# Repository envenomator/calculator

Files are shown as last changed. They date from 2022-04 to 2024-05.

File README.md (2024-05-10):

# Barebones AVR m328p based programmer's calculator

I was in need of a no-frills, programmer's calculator, not satisfied with the SwissMicros DM16L clone (which uses RPN), I decided to design my own.
This version powers from a USB micro cable, uses the waveshare 2inch 320x240 color display. Complete insanity, but I like it a lot.

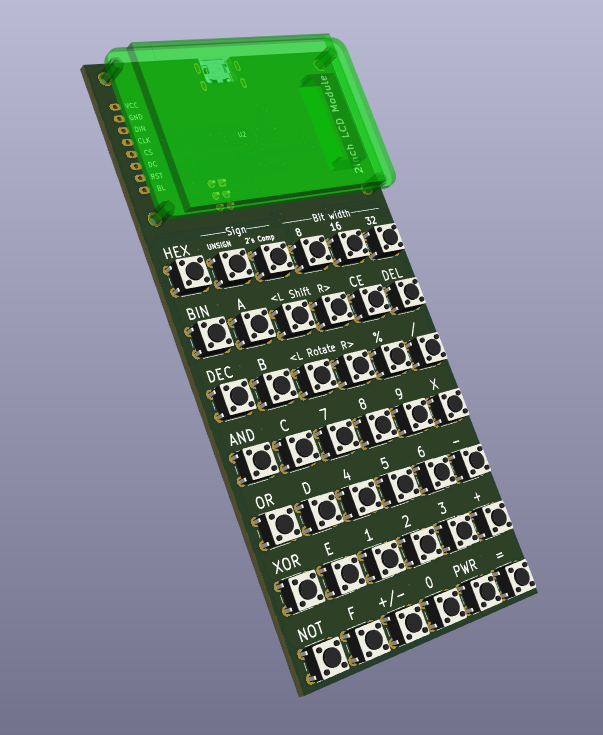
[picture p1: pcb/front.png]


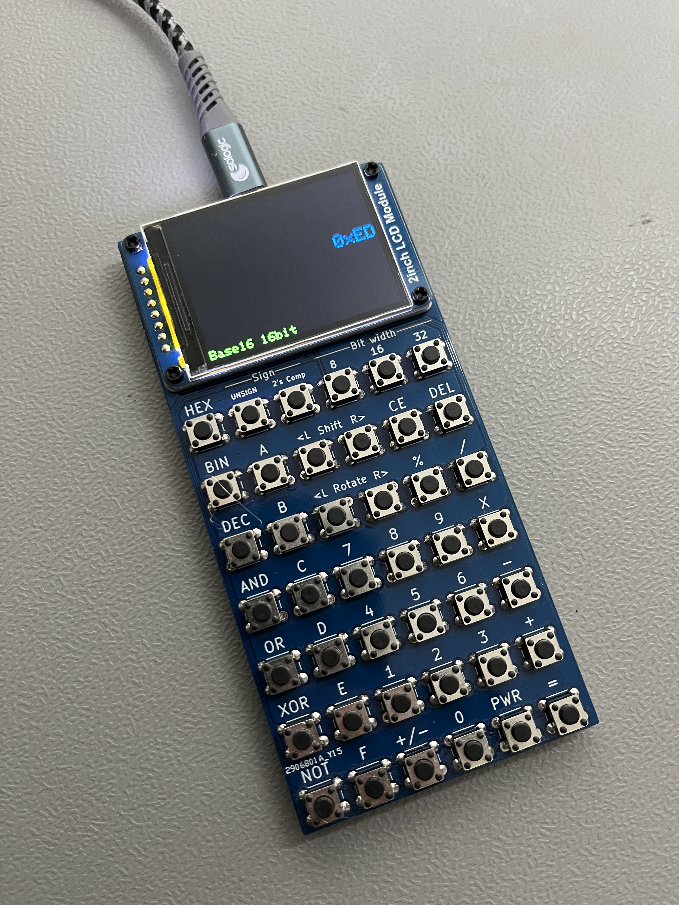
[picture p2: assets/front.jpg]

The display is mounted to the PCB using two 2mm plastic screws, using a 3d printed shim as standoff.


The calculator with it's back plate glued on, programming port accessible.

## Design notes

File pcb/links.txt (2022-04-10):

https://simple-circuit.com/arduino-i2c-lcd-pcf8574/
https://webshop.domoticx.nl/index.php?route=product/product&product_id=266

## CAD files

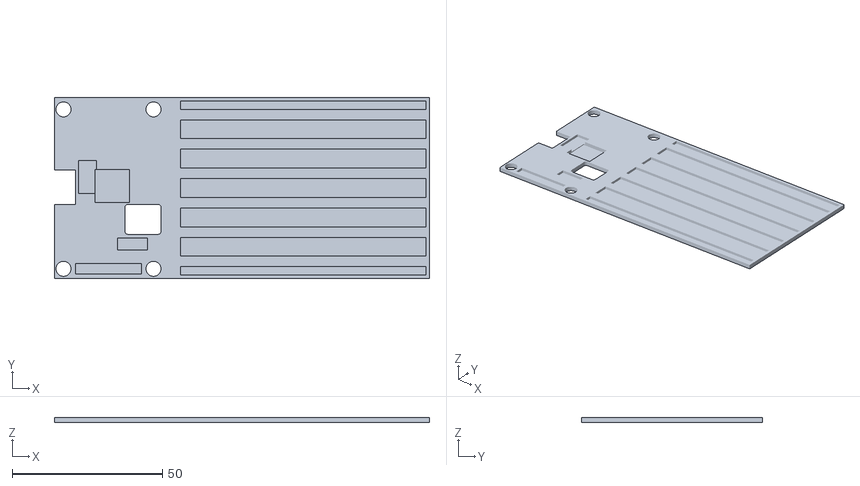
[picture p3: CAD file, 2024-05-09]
Calculator_bottom.stl
125.0 x 60.4 x 1.80

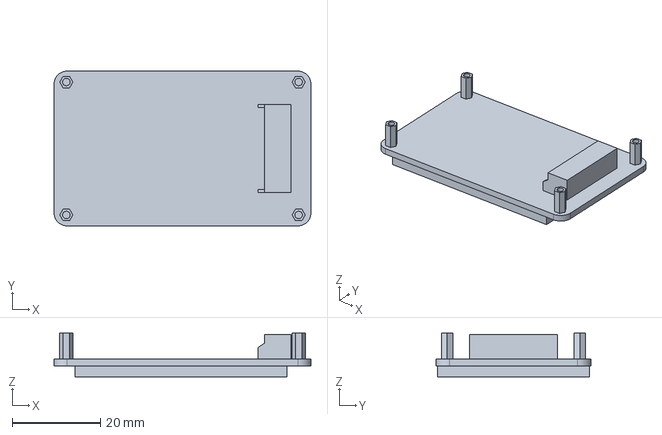
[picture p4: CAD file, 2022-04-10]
pcb/2inch LCD Module 3D Drawing/1018a.stp
58.4 x 35.2 x 9.90 mm

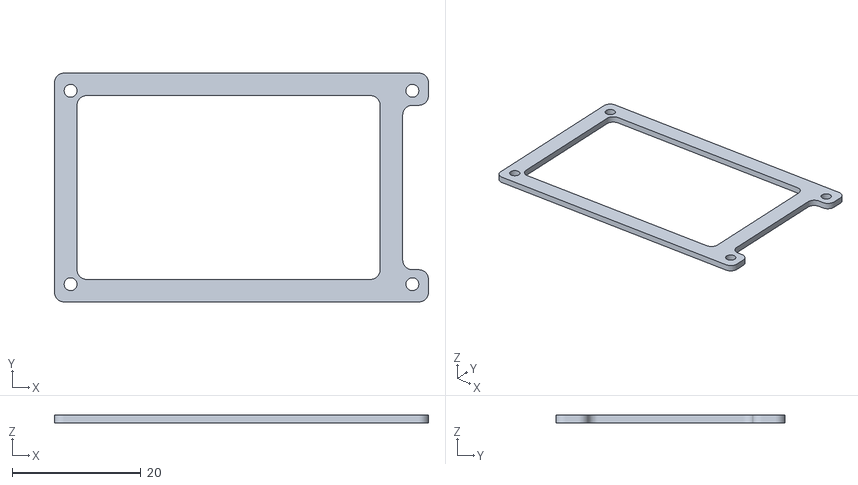
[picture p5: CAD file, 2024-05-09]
LCD_shim_calculator v4.stl
58.0 x 35.5 x 1.20

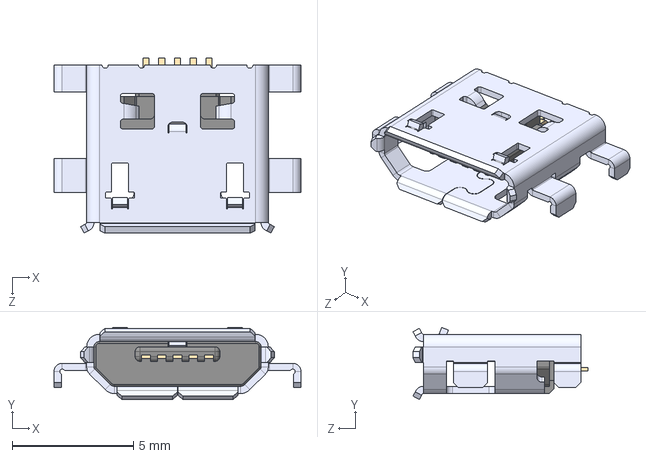
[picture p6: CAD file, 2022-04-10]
pcb/47642-0001/47642-0001.step
10.2 x 2.97 x 7.23 mm

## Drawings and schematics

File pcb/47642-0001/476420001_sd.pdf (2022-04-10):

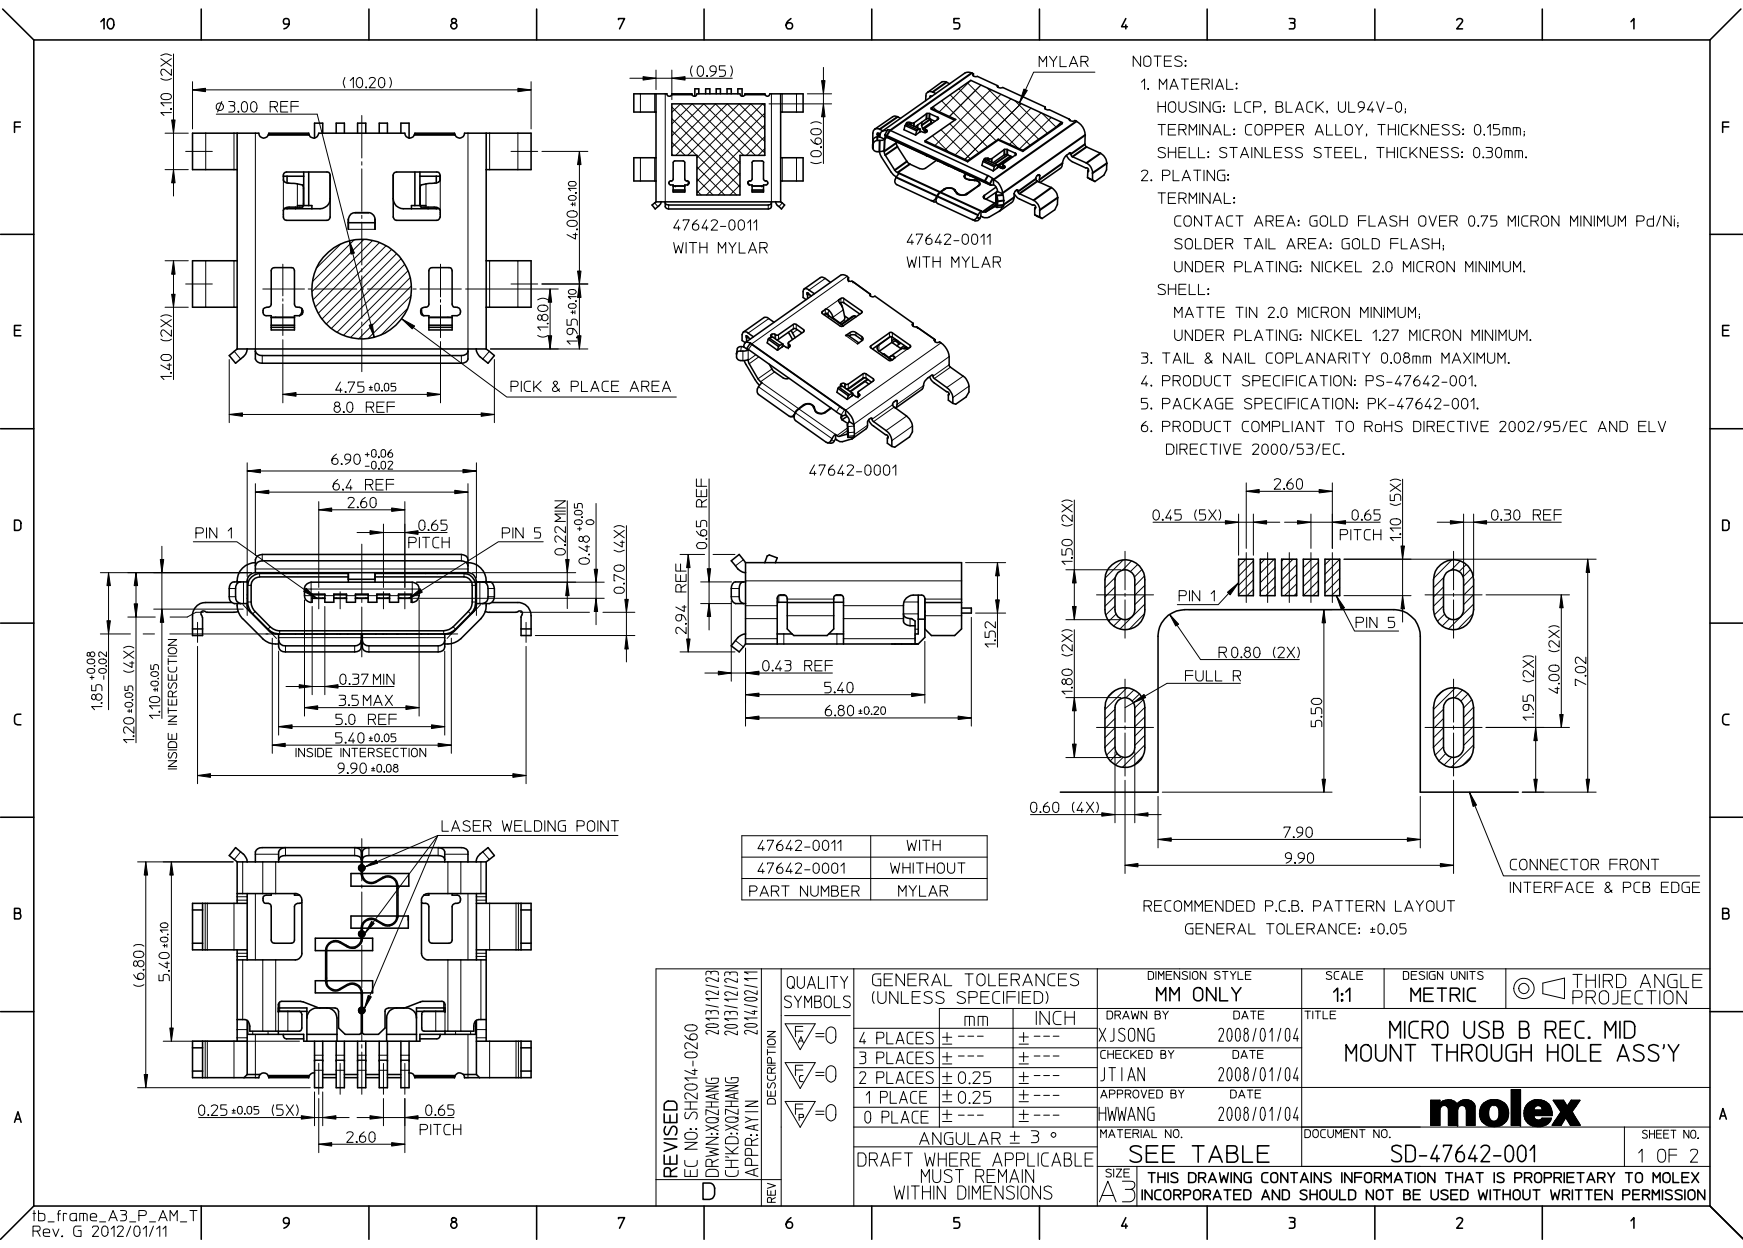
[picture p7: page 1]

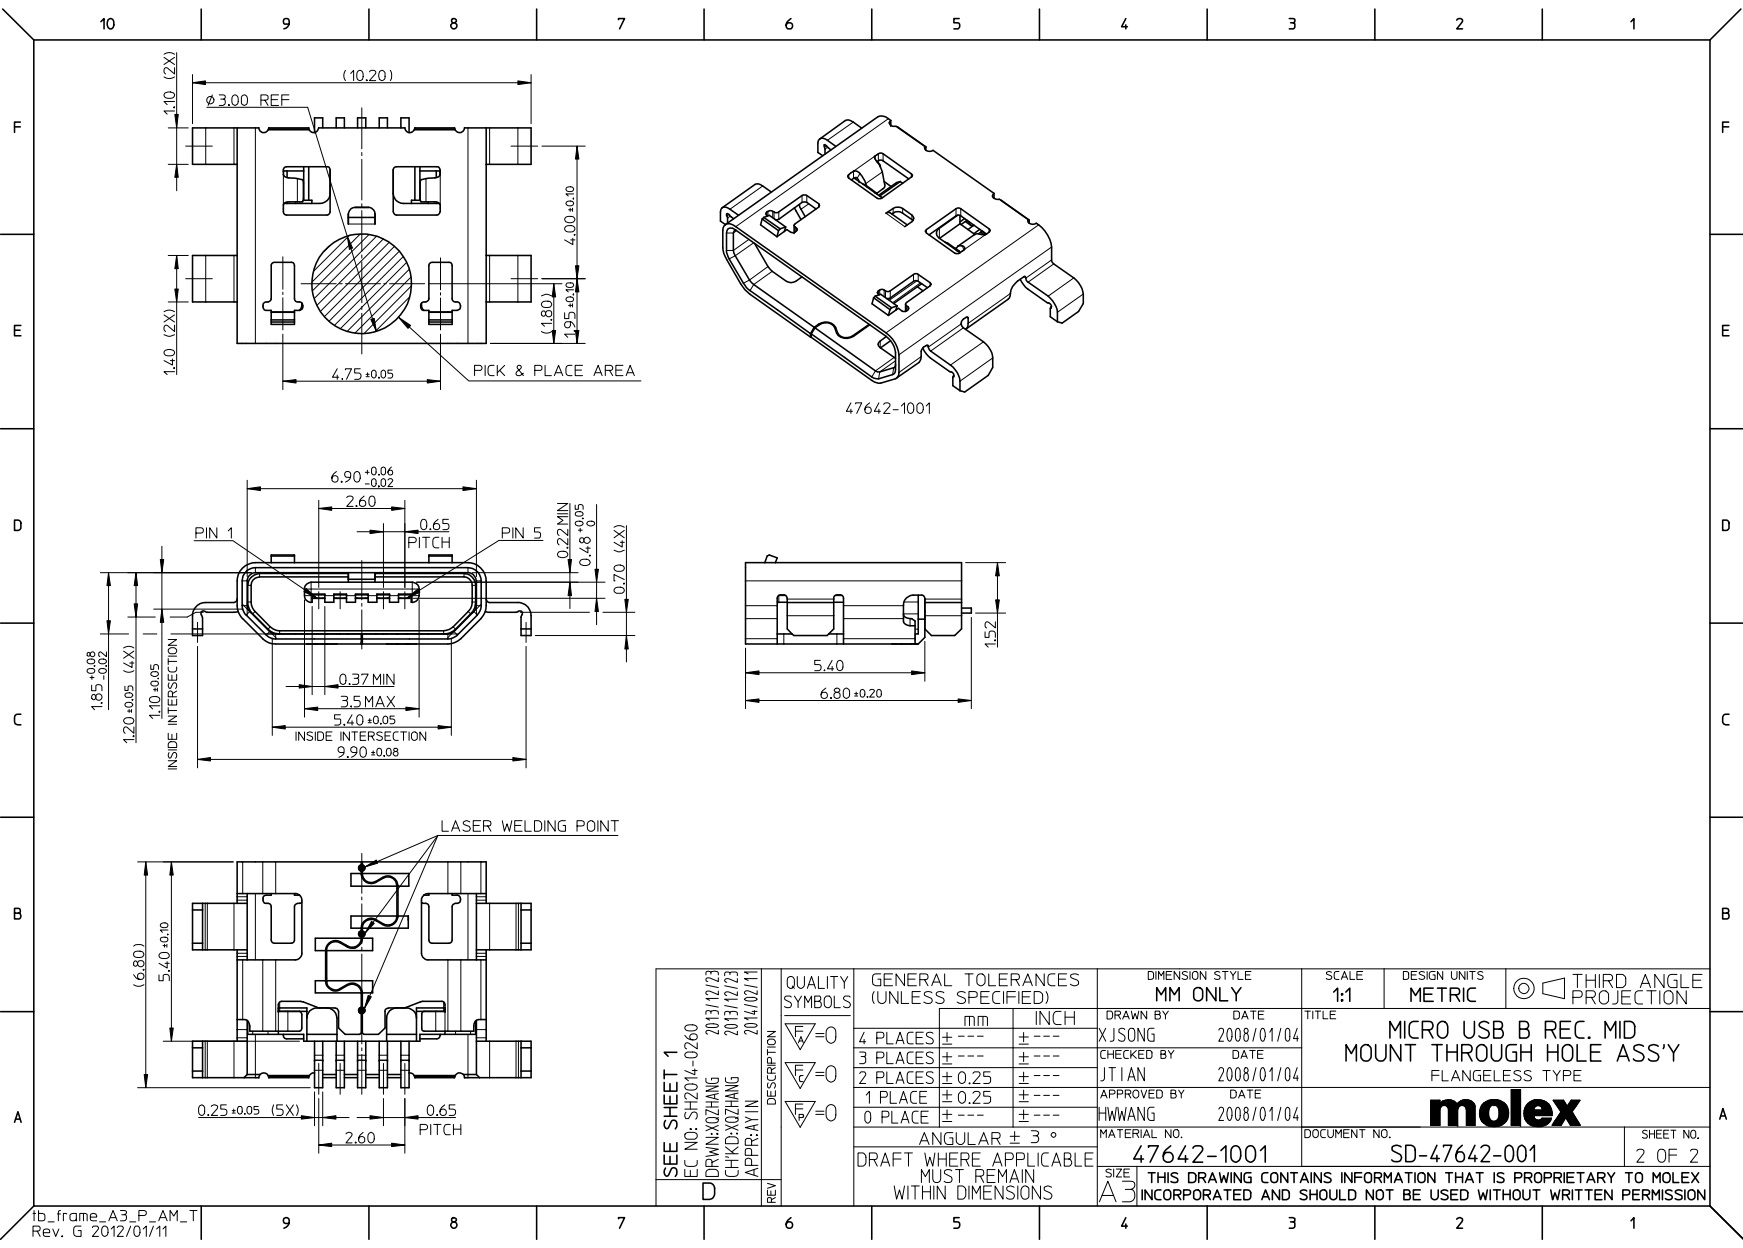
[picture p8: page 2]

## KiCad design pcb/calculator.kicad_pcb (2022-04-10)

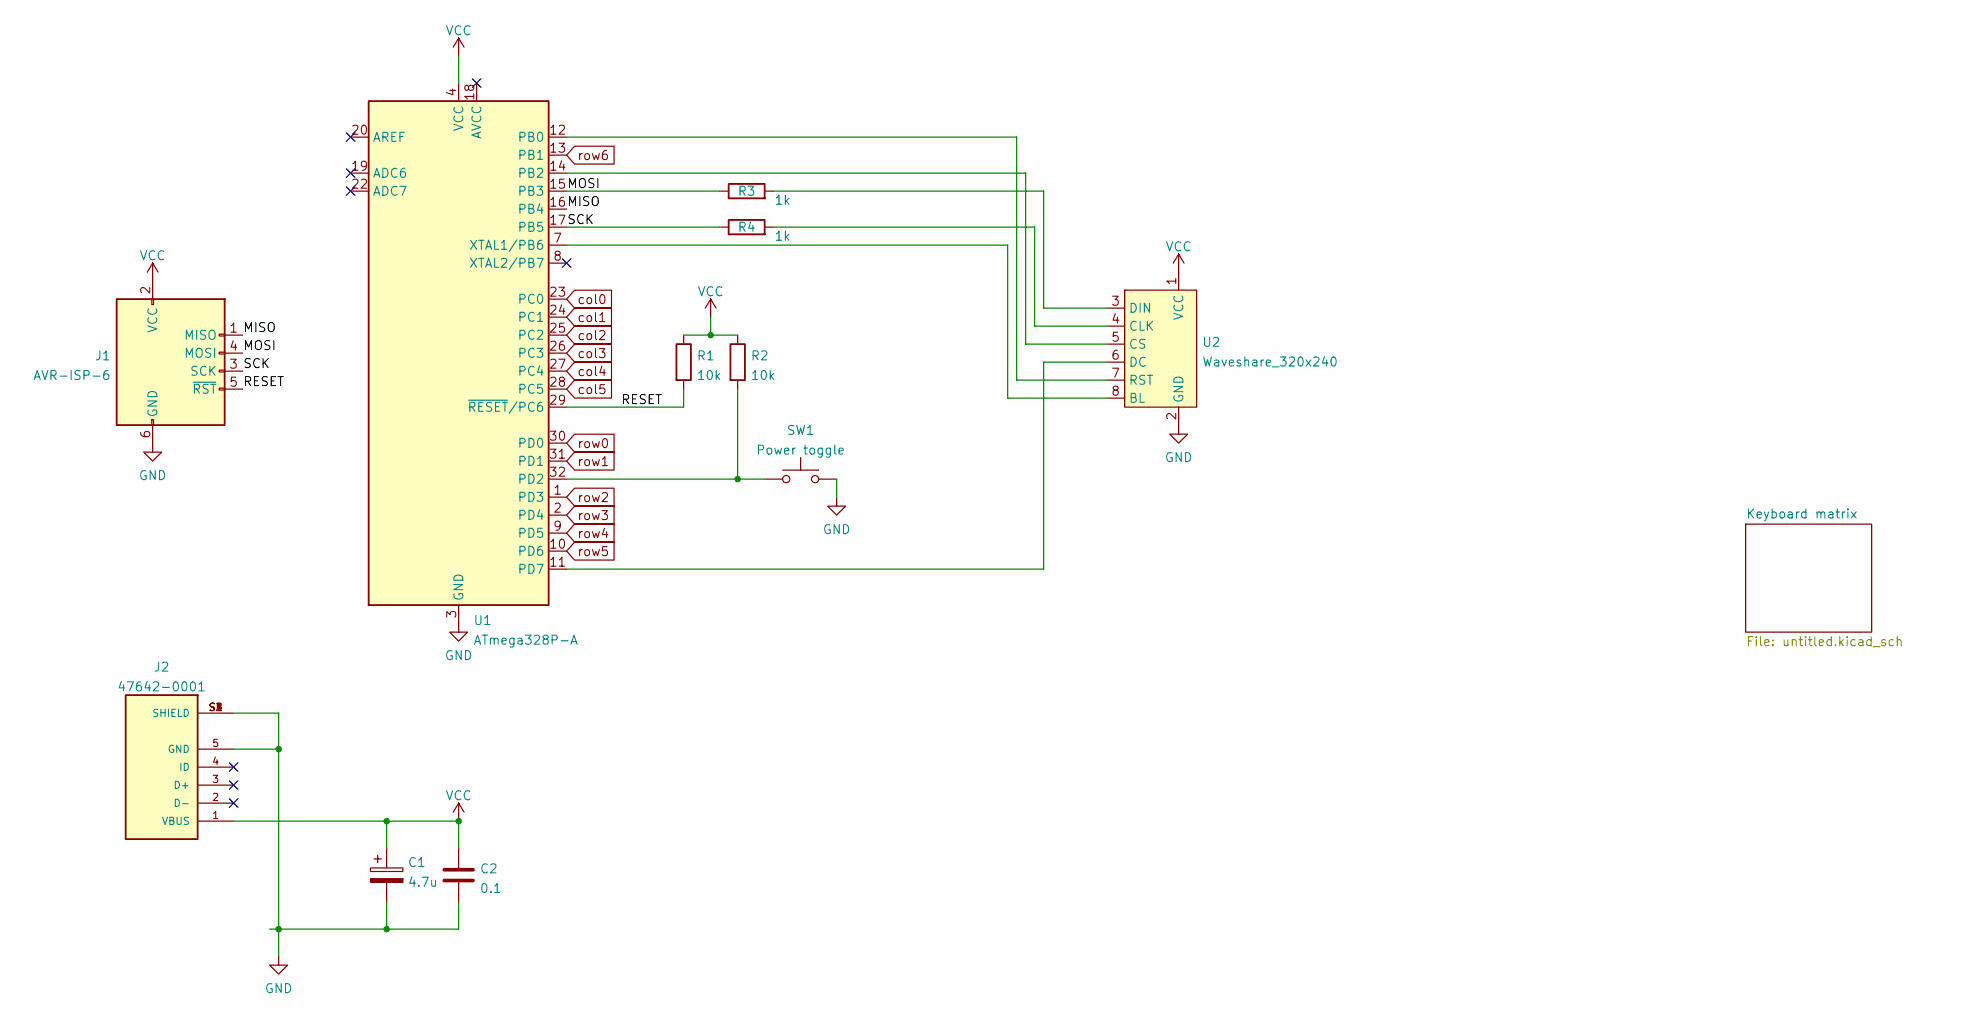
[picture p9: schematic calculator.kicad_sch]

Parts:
C1: 4.7u; C_0805_2012Metric_Pad1.18x1.45mm_HandSolder
C2: 0.1; C_0805_2012Metric_Pad1.18x1.45mm_HandSolder
J1: AVR-ISP-6; PinHeader_2x03_P2.54mm_Vertical
J2: 47642-0001; MOLEX_47642-0001
R1, R2: 10k; R_0805_2012Metric_Pad1.20x1.40mm_HandSolder
R3, R4: 1k; R_0805_2012Metric_Pad1.20x1.40mm_HandSolder
SW1: Power toggle; SW_PUSH_6mm
U1: ATmega328P-A; TQFP-32_7x7mm_P0.8mm
U2: Waveshare_320x240

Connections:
/MISO: J1.1 (MISO), U1.16 (PB4)
/MOSI: J1.4 (MOSI), R3.1, U1.15 (PB3)
/RESET: J1.5 (~RST), R1.2, U1.29 (~RESET/PC6)
/SCK: J1.3 (SCK), R4.1, U1.17 (PB5)
GND: C1.2, C2.2, J1.6 (GND), J2.5 (GND), J2.S1 (SHIELD), J2.S2 (SHIELD), J2.S3 (SHIELD), J2.S4 (SHIELD), SW1.2, U1.3 (GND), U1.5 (GND), U1.21 (GND), U2.2 (GND)
unnamed: R2.2, SW1.1, U1.32 (PD2)
unnamed: R3.2, U2.3 (DIN)
unnamed: R4.2, U2.4 (CLK)
unnamed: U1.7 (XTAL1/PB6), U2.8 (BL)
unnamed: U1.11 (PD7), U2.6 (DC)
unnamed: U1.12 (PB0), U2.7 (RST)
unnamed: U1.14 (PB2), U2.5 (CS)
VCC: C1.1, C2.1, J1.2 (VCC), J2.1 (VBUS), R1.1, R2.1, U1.4 (VCC), U1.6 (VCC), U2.1 (VCC)
col0: U1.23 (PC0); also elsewhere on the board
col1: U1.24 (PC1); also elsewhere on the board
col2: U1.25 (PC2); also elsewhere on the board
col3: U1.26 (PC3); also elsewhere on the board
col4: U1.27 (PC4); also elsewhere on the board
col5: U1.28 (PC5); also elsewhere on the board
row0: U1.30 (PD0); also elsewhere on the board
row1: U1.31 (PD1); also elsewhere on the board
row2: U1.1 (PD3); also elsewhere on the board
row3: U1.2 (PD4); also elsewhere on the board
row4: U1.9 (PD5); also elsewhere on the board
row5: U1.10 (PD6); also elsewhere on the board
row6: U1.13 (PB1); also elsewhere on the board

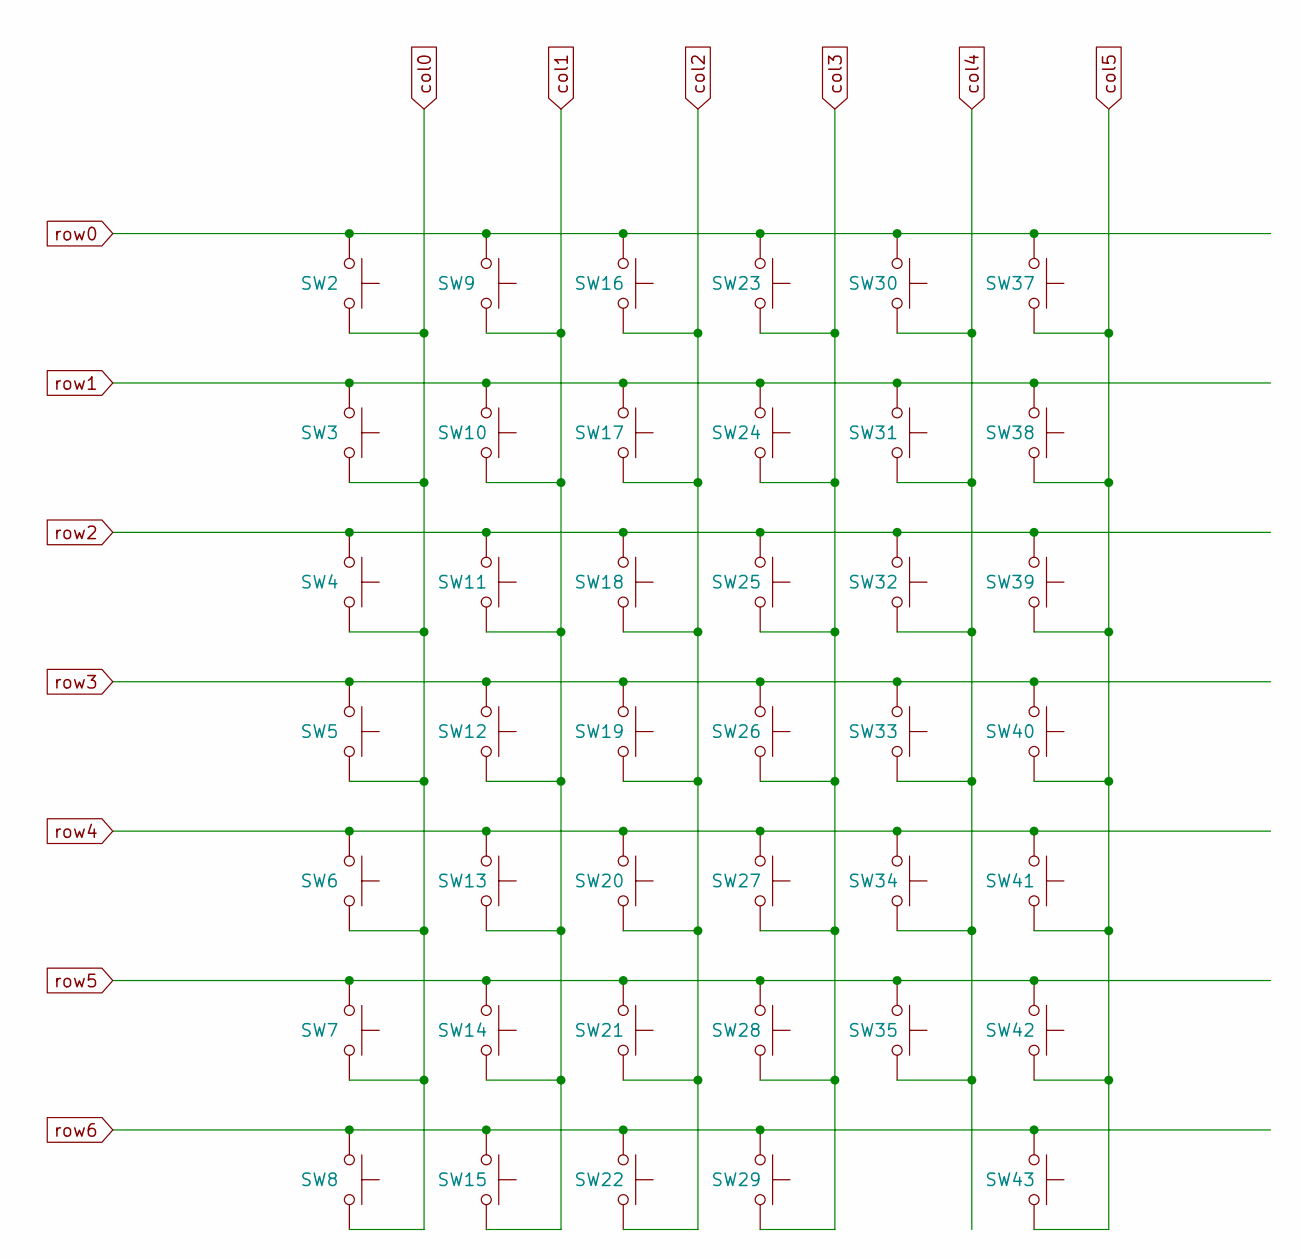
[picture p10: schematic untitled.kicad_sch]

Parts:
SW2: HEX; SW_PUSH_6mm
SW3, SW4, SW5, SW6, SW7, SW8, SW9, SW10, SW11, SW12, SW13, SW14, SW15, SW16, SW17, SW18, SW19, SW20, SW21, SW22, SW23, SW24, SW25, SW26, SW27, SW28, SW29, SW30, SW31, SW32, SW33, SW34, SW35, SW37, SW38, SW39, SW40, SW41, SW42, SW43: SW_Push; SW_PUSH_6mm

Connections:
col0: SW2.2, SW3.2, SW4.2, SW5.2, SW6.2, SW7.2, SW8.2; also elsewhere on the board
col1: SW9.2, SW10.2, SW11.2, SW12.2, SW13.2, SW14.2, SW15.2; also elsewhere on the board
col2: SW16.2, SW17.2, SW18.2, SW19.2, SW20.2, SW21.2, SW22.2; also elsewhere on the board
col3: SW23.2, SW24.2, SW25.2, SW26.2, SW27.2, SW28.2, SW29.2; also elsewhere on the board
col4: SW30.2, SW31.2, SW32.2, SW33.2, SW34.2, SW35.2; also elsewhere on the board
col5: SW37.2, SW38.2, SW39.2, SW40.2, SW41.2, SW42.2, SW43.2; also elsewhere on the board
row0: SW2.1, SW9.1, SW16.1, SW23.1, SW30.1, SW37.1; also elsewhere on the board
row1: SW3.1, SW10.1, SW17.1, SW24.1, SW31.1, SW38.1; also elsewhere on the board
row2: SW4.1, SW11.1, SW18.1, SW25.1, SW32.1, SW39.1; also elsewhere on the board
row3: SW5.1, SW12.1, SW19.1, SW26.1, SW33.1, SW40.1; also elsewhere on the board
row4: SW6.1, SW13.1, SW20.1, SW27.1, SW34.1, SW41.1; also elsewhere on the board
row5: SW7.1, SW14.1, SW21.1, SW28.1, SW35.1, SW42.1; also elsewhere on the board
row6: SW8.1, SW15.1, SW22.1, SW29.1, SW43.1; also elsewhere on the board

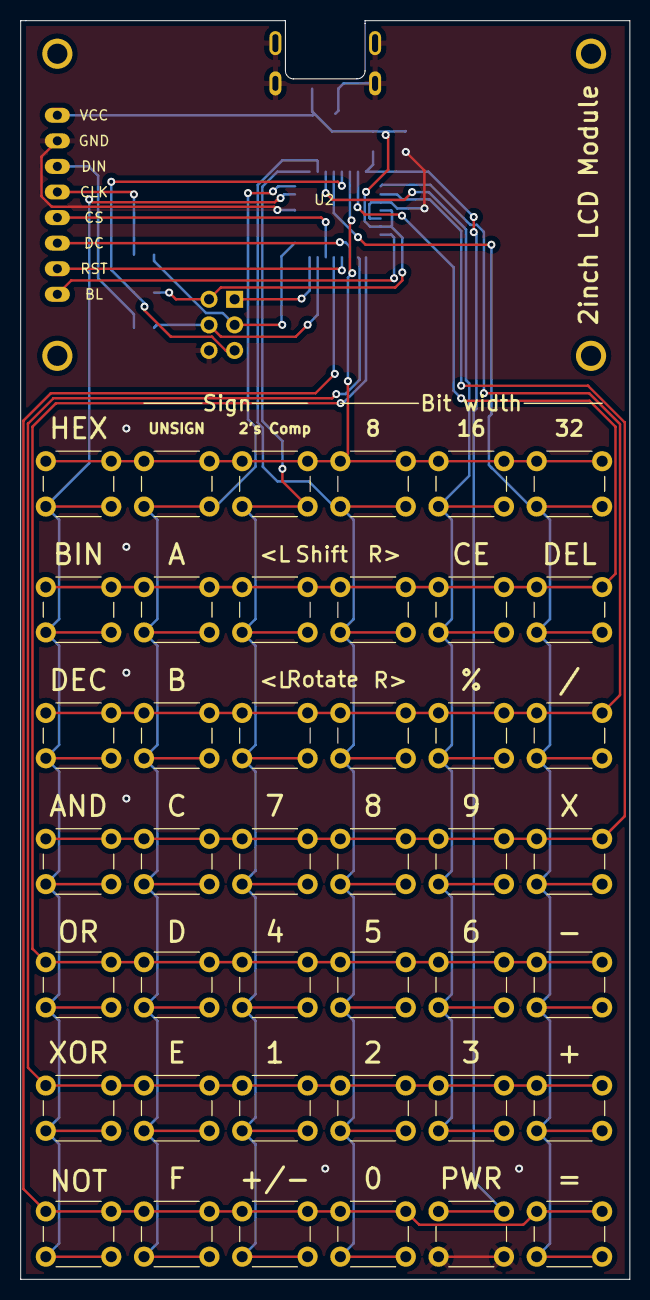
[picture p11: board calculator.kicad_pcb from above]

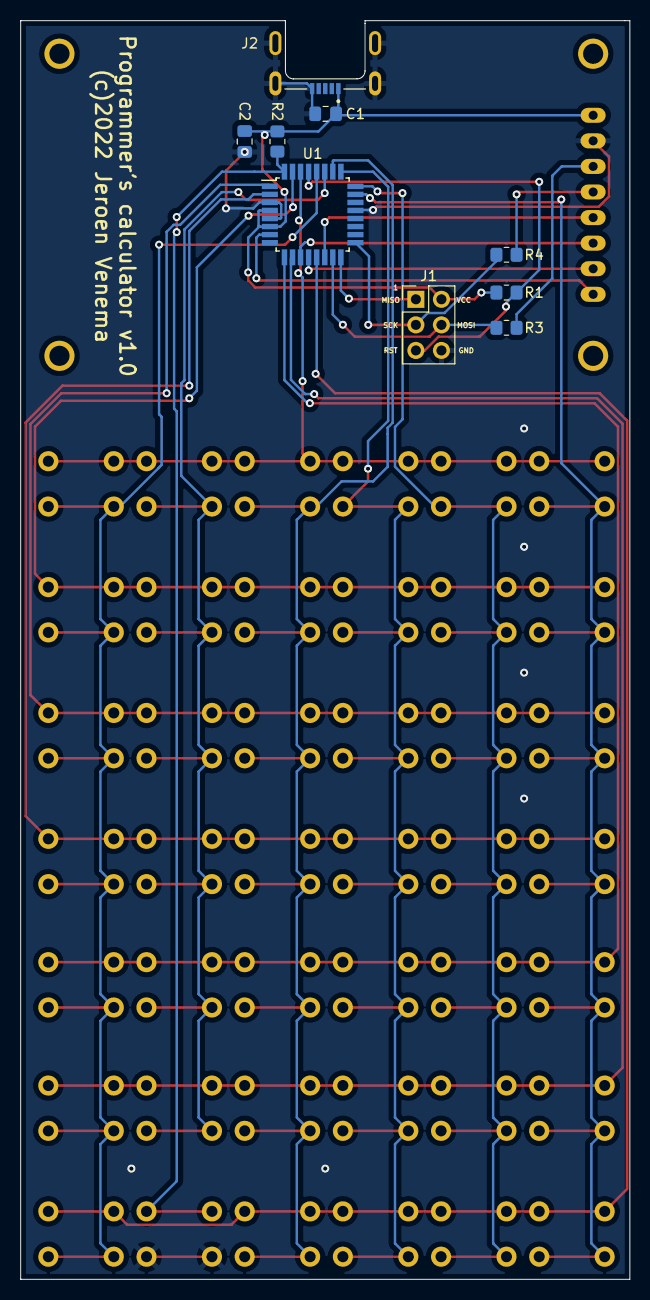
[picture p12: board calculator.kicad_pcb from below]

Board: 2 copper layers, 60.5 x 125.0 mm, 52 parts (9 on the bottom side), 26 nets.

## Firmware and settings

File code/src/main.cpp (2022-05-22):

// GFX library font dimensions, in pixels:
// 1: X/Y: 5+1 / 7+1
// 2: X/Y: 10+2/14+2
// 3: X/Y: 15+3/21+3
// + denotes spacing between glyphs

#include <avr/io.h>
#include <avr/sleep.h>
#include <util/delay.h>
#include <avr/interrupt.h>
#include <avr/power.h>
#include <Arduino.h>
#include <Keypad.h>
#include <Adafruit_GFX.h>    // Core graphics library
#include <Adafruit_ST7789.h> // Hardware-specific library for ST7789
#include <SPI.h>
#include <TimerOne.h>        // used for automatic shutdown timer
#include "displayvalue.h"
#include "inputbox.h"
#include "area.h"
#include "statusmessage.h"
#include "statusflags.h"
#include "operation.h"

// TFT Screen setup
#define TFT_CS        10
#define TFT_RST        8
#define TFT_DC         7
Adafruit_ST7789 tft = Adafruit_ST7789(TFT_CS, TFT_DC, TFT_RST);

// Custom colors
#define TFT_LIGHTGREY 0x9cf3
#define TFT_DARKBLUE  0x0015

// Timer
#define TIMER_US 100000                         // 100mS set timer duration in microseconds 
#define TICK_COUNTS 600                         // 60S worth of timer ticks
volatile long tick_count = TICK_COUNTS;         // Counter for 10S

// Matrix keypad setup
const byte ROWS = 7;
const byte COLS = 6;
char keys[ROWS][COLS] = {   //CAPS and numbers are direct input, lower-case are commands
  {'h','u','s','i','j','k'},
  {'b','A','l','r','c','X'},
  {'d','B','m','n','%','/'},
  {'a','C','7','8','9','*'},
  {'o','D','4','5','6','-'},
  {'x','E','1','2','3','+'},
  {'!','F','^','0','p','='} // p isn't mapped to the grid
};
byte rowPins[ROWS] = {0,1,3,4,5,6,9};
byte colPins[COLS] = {14,15,16,17,18,19};
Keypad keypad = Keypad( makeKeymap(keys), rowPins, colPins, ROWS, COLS );

// value setup
displayValue result(0,status::Hex, 16, false);  // default Decimal mode, start from 0, nothing to show
inputBox input(0,status::Hex,16, false);          // default Decimal mode, start from 0, show value

// status box
statusMessage currentstatus(0, status::Hex, 16, false);
statusFlags flags;
operation op;

void wakeUpNow()
{
}  

void sleepNow()
{
  set_sleep_mode(SLEEP_MODE_PWR_DOWN);
  sleep_enable();
  attachInterrupt(0,wakeUpNow,LOW);
  sleep_mode();
  detachInterrupt(0);
}

// --------------------------
// timerIsr() 100 milli second interrupt ISR()
// Called every time the hardware timer 1 times out.
// --------------------------
void timerIsr()
{
  // count down to zero, don't restart. Main loop will pick up on zero
  if(tick_count) tick_count--;
}

void setup(void) {
  // Screen init
  tft.init(240, 320);           // Init ST7789 320x240
  tft.setRotation(1);
  tft.fillScreen(ST77XX_BLACK);

  // attach screen object and asign area to each output object
  result.init(&tft, area(0,0,319,23), ST77XX_WHITE, TFT_LIGHTGREY);
  flags.init(&tft,area(0,30,319,46), ST77XX_YELLOW);
  op.init(&tft, area(0,75,319,99), ST77XX_BLUE);
  input.init(&tft, area(0,100,319,129), ST77XX_BLUE, TFT_DARKBLUE);
  currentstatus.init(&tft, area(0,224,319,239), ST77XX_GREEN);
  
  // set backlight pin to on
  DDRB |= (1 << 6);
  PORTB |= (1 << 6); // set bit 6 on for backlight (BL)

  // PWR button is an input
  pinMode(2, INPUT);  // PWR button connected to PIN 2

  // show default objects on screen
  input.show();
  currentstatus.show();

  // Countdown timer start
  Timer1.initialize(TIMER_US);                  // Initialise timer 1
  Timer1.attachInterrupt( timerIsr );           // attach the ISR routine here

}

void loop() {
  char key = keypad.getKey();

  if(key)
  {
    tick_count = TICK_COUNTS; // reset timer

    switch(key)
    {
      case '0' ... '9':
      case 'A' ... 'F':
        input.processKeyValue(key);
        break;
      case 'X':
        input.deleteDigit();
        break;
      case 'c': // Clear
        result.hide();
        result.setValue(0); // no results
        op.hide();
        op.set(operation::Method::None);
        flags.hide();
        flags.clearFlags();
        input.setValue(0);
        break;
      case 'h':
        currentstatus.setBase(status::Hex);
        input.setBase(status::Hex);
        result.setBase(status::Hex);
        break;
      case 'b':
        currentstatus.setBase(status::Bin);
        input.setBase(status::Bin);
        result.setBase(status::Bin);
        break;
      case 'd':
        currentstatus.setBase(status::Dec);
        input.setBase(status::Dec);
        result.setBase(status::Dec);
        break;
      case 'i': // 8-bit mode
        currentstatus.setBitLength(8);
        input.setBitLength(8);
        //result.hide();
        result.setBitLength(8);
        break;
      case 'j': // 16-bit mode
        currentstatus.setBitLength(16);
        input.setBitLength(16);
        //result.hide();
        result.setBitLength(16);
        break;
      case 'k': // 32-bit mode 
        currentstatus.setBitLength(32);
        input.setBitLength(32);
        //result.hide();
        result.setBitLength(32);
        break;
      case 's': // change to 2s complement in Dec mode
        if(input.getBase() == status::Dec)
        {
          input.setSign(true);
          result.setSign(true);
          currentstatus.setSign(true);
        }
        break;
      case 'u': // change to unsigned
        if(input.getBase() == status::Dec)
        {
          input.setSign(false);
          result.setSign(false);
          currentstatus.setSign(false);
        }
        break;
      case '^': // change sign, if signed decimal
        if(input.getBase() == status::Dec && input.getSign())
        {
            input.negateDisplay();
        }
        break;
      case '!': // Bitwise NOT
        if(result.getValue() != 0 && input.getValue() == 0)
          result.setValue(~(result.getValue()));
        else
          result.setValue(~(input.getValue()));
        result.show();
        flags.setFlags(false,status::isNegative(result.getValue(),result.getBitLength()),false);
        flags.show();
        op.hide();
        op.set(operation::None);
        input.setValue(0);
        break;
      case '=':
        // clear old flags first
        if(!op.inProgress()) result.setValue(input.getValue());
        // always perform an operation at =, even 'None'
        result.setValue(op.perform(result.getValue(),input.getValue(),input.getBitLength(),input.getBase(),input.getSign()));
        result.show();
        flags.setFlags(op.getCarry(),status::isNegative(result.getValue(),result.getBitLength()),op.getOverflow());
        flags.show();
        // wait for any errors
        if(op.error())
        { 
          op.showError();
          while(op.error()) // blocked wait until user acknowledges error
          {
            key = keypad.getKey();
            if(key == 'c' || key == 'X') op.clearError();
          }
        }
        // clear operation and reset input
        op.hide();
        op.set(operation::None);
        input.setValue(0);
        break;
      default: // Operators with two operands
        if(!op.inProgress())  // only one operator at a time
        {
          // Select previous result, or current input
          if(input.getValue() != 0)
            result.setValue(input.getValue());
          else
            result.setValue(result.getValue());
          result.show();
          switch(key)
          {
            case 'a': // AND
              op.set(operation::And);
              break;
            case 'o': // OR
              op.set(operation::Or);
              break;
            case 'x': // XOR
              op.set(operation::Xor);
              break;
            case 'l': // LSHIFT
              op.set(operation::SL);
              break;
            case 'r': // RSHIFT
              op.set(operation::SR);
              break;
            case 'm': // Rotate Left
              op.set(operation::RL);
              break;
            case 'n': // Rotate Right
              op.set(operation::RR);
              break;
            case '%': // Modulo
              op.set(operation::Modulo);
              break;
            case '/': // Divide
              op.set(operation::Divide);
              break;
            case '*':
              op.set(operation::Multiply);
              break;
            case '-':
              op.set(operation::Minus);
              break;
            case '+':
              op.set(operation::Plus);
          }
          op.show();
          input.setValue(0);
        }
        break;
    }
  }

  if(digitalRead(2) == 0 || tick_count == 0)
  {
    PORTB &= ~(1 << 6); // backlight off
    while(digitalRead(2) == 0);
    sleepNow();
    delay(50);  // debounce button
    while(digitalRead(2) == 0); // wait for button release
    PORTB |= (1 << 6);  // backlight back on again
    tick_count = TICK_COUNTS; // reset timer
  }
}

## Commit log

2022-05-22 60s shutdown timerafter each keypress
2024-05-09 Add files via upload
    Shim to lower the LCD to the underlying PCB
    [LCD_shim_calculator v4.stl]

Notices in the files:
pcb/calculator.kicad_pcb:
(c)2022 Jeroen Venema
